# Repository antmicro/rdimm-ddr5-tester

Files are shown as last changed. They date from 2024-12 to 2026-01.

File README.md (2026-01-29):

# Data Center RDIMM DDR5 Tester

Copyright (c) 2021-2026 [Antmicro](https://antmicro.com)



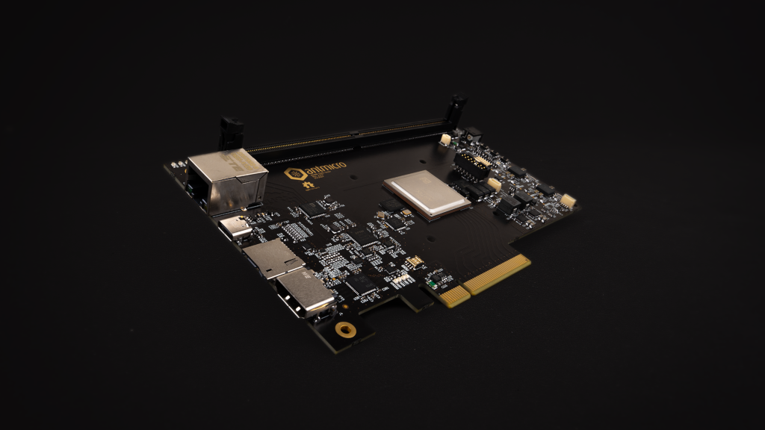
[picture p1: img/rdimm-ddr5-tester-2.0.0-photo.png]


## Overview

This project contains open hardware KiCad design files for an experimental, FPGA-based platform for interfacing with RDIMM DDR5 RAM modules.
The latest design revision (Rev.2.x) features an AMD Artix UltraScale Plus FPGA.
The design files are now being verified with a small series of prototypes.
The [previous revision](https://github.com/antmicro/ddr5-tester/releases/tag/rev.1.0.1-production) (Rev.1.x) was built around an AMD (Xilinx) Kintex-7 FPGA and the design files were verified with prototypes.
This hardware DDR5 testing platform integrates with the open source [Rowhammer Tester](https://github.com/antmicro/rowhammer-tester) project.

## Project structure

The main repository directory contains KiCad PCB project files, a LICENSE and README.
The remaining files are stored in the following directories:

* `img` - contains graphics for this README
* `assets` - contains visual assets for showcasing this design on [Open Hardware Portal](https://openhardware.antmicro.com/boards/data-center-rdimm-ddr5-tester/?view=top-ortho&tab=features).

## Key features

* Artix Ultrascale plus FPGA (AU25P)
* RDIMM DDR5 memory slot
* PCIe 8x Edge connector
* HDMI output connector
* Ethernet RJ45 connector with 1GbE transceiver
* USB-C debug connector with FT4232HQ FTDI USB controller
* JTAG connector
* microSD card slot
* 16 MBytes S25FL128S QSPI FLASH memory
* IS66WVH16M8DBLL HyperRAM
* External 7-15V DC power input

## License

This project is published under the [Apache-2.0](LICENSE) license.

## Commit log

2024-09-24 [#65754] Rev 2.0.0 Initial commit - source design files from so-dimm-ddr5-tester e0a54f86
    [DDR5.kicad_sch, config-spi.kicad_sch, data-center-rdimm-ddr5-tester.kicad_sch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]
2024-09-24 [#65754] Update PCB outline and rename the board
    [rdimm-ddr5-tester-ultrascale-plus.kicad_sch]
2024-09-24 [#65754] Replace so-dimm with rdimm connector
    [ddr5-rdimm.kicad_sch, rdimm-ddr5-tester-ultrascale-plus.kicad_sch]
2024-09-25 [#66311] Add XCAU25P. Reconnect configuration bank 0
    [fpga-bank-14.kicad_sch, fpga-banks-32-34.kicad_sch, fpga-config.kicad_sch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]
2024-09-25 [#66300] Add recommended FPGA supply voltages
    [fpga-power.kicad_sch]
2024-09-25 [#66312] Reconnect PCIe to GTX 224
    [fpga-mgt.kicad_sch]
2024-09-25 [#66329] Replace memory connector on PCB
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2024-09-26 [#66300] Connect supply domains to FPGA. Adjust decoupling
    [fpga-power.kicad_sch]
2024-09-26 [#66312] Reconnect GTY 224 and 225 for x8 PCIe configuration
    [fpga-mgt.kicad_sch]
2024-09-26 [#66329] Replace the FPGA on PCB
2024-09-26 [#66312] Connect x8 PCIe
    [data-center-rdimm-ddr5-tester.kicad_sch, fpga-mgt.kicad_sch, pcie-connector.kicad_sch]
2024-09-26 [#66329] Replace PCIe connector
2024-09-26 [#66329] Designate the heat sink as mechanical
    [data-center-rdimm-ddr5-tester.kicad_sch]
2024-09-27 [#66311] Add TMP451 remote temperature sensor
    [fpga-config.kicad_sch]
2024-09-27 [#66300] Start reconnecting power supply to support US+ voltages and power sequence
    [supply.kicad_sch]
2024-09-30 [66521] Rename kicad_sch file
    [data-center-rdimm-ddr5-tester.kicad_sch, fpga-hp-banks.kicad_sch]
2024-09-30 [#66300] Add 30A VCCINT supply
    [supply.kicad_sch]
2024-09-30 [#66521] Add pinout rev.1.1.0 connection to the schematic
    [fpga-hp-banks.kicad_sch]
2024-10-01 [#66521] Connect labels to DDR5 connector - define DDR5_RDIMM bus
    [data-center-rdimm-ddr5-tester.kicad_sch, ddr5-rdimm.kicad_sch, fpga-hp-banks.kicad_sch]
2024-10-01 [#66300] Finish reconnecting power supply to support US+ voltages and power sequence
    [supply.kicad_sch]
2024-10-23 [#66311] Replace HyperRam and Flash with 1V8 parts. Add 1V25 ADC VREF for core temp measurement (internal)
    [fpga-config.kicad_sch, fpga-power.kicad_sch, hyperram-flash.kicad_sch]
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2024-10-23 [#66521] Rename DQS pairs
    [ddr5-rdimm.kicad_sch, fpga-hp-banks.kicad_sch]
2024-10-23 [#66521] Add Layout for DDR5 A.DQ[0..15]
    [data-center-rdimm-ddr5-tester.kicad_sch, fpga-hp-banks.kicad_sch]
2024-10-23 [#66521] Add Layout for DDR5 B.DQ[24..31]
    [fpga-hp-banks.kicad_sch]
2024-10-23 [#66727] Reconnect HyperRam and ETH RGMII to HP bank 67
    [fpga-bank-12.kicad_sch, fpga-hp-banks.kicad_sch]
2024-10-23 [#66727] Reconfigure ETH PHY IO voltage to 1V8
    [ethernet.kicad_sch]
2024-10-23 [#66521] Add Layout for DDR5 Channel B
    [fpga-hp-banks.kicad_sch]
2024-10-23 [#66521] Add Layout for DDR5 A.DQ[0..23]
    [fpga-hp-banks.kicad_sch]
2024-10-23 [#66300] Replace MGTACC and MGTAVTT high side current measurement resistor, optimize decoupling
    [fpga-power.kicad_sch, supply.kicad_sch]
2024-10-23 [#66300] Replace power measurement IC's with PAC1720 and PAC1944. Split supply sheet to hierarchical structure. Add missing VCCINT pull-up resistors. Change power meters supply to 3V3_AON
    [dc-dc-aux-mgt.kicad_sch, dc-dc-io.kicad_sch, dc-dc-vccint.kicad_sch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]
2024-10-23 [#66312] Add HDMI driver. Connect TMDS to GTH quad 226
    [fpga-mgt.kicad_sch]
2024-10-23 [#66521] Add Layout for DDR5 B.CB[0..7]
    [fpga-hp-banks.kicad_sch]
2024-10-23 [#66521] Add Layout for DDR5 A.DQ[23..31]
    [fpga-hp-banks.kicad_sch]
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2024-10-23 [#66300] Replace HDMI output driver to SN75DP159
    [fpga-mgt.kicad_sch]
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2024-10-23 [#66727] Move remaining signals to HD banks sheet
    [fpga-hd-banks.kicad_sch]
2024-10-23 [#66727] Finish connecting HDMI driver. Add SD card logic level converter. Add SD 3.0 support
    [data-center-rdimm-ddr5-tester.kicad_sch, fpga-mgt.kicad_sch, hdmi-sd-card.kicad_sch]
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2024-10-23 [#66727] Change FTDI JTAG voltage level to 1V8
    [debug-ftdi.kicad_sch]
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2024-10-23 [#67016] Add RGMII, Hyper Ram and SD card schematic connection
    [data-center-rdimm-ddr5-tester.kicad_sch, fpga-hp-banks.kicad_sch]
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2024-10-23 [#66311] Connect 1V25 VREF negative signal to GND
    [fpga-config.kicad_sch]
2024-10-23 [#66311] Start connecting HDMI RX to GTH226 quad
    [fpga-mgt.kicad_sch, hdmi-sd-card.kicad_sch]
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2024-10-23 [#66727] Fix schematic errors
    [dc-dc-vccint.kicad_sch, fpga-config.kicad_sch, fpga-hp-banks.kicad_sch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]
2024-10-23 [#66727] Route VCCINT sense. Route VREF. Place supply power meters circuits
    [dc-dc-vccint.kicad_sch, fpga-config.kicad_sch]
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2024-10-23 [#67402] Connect low speed signals and interfaces to the HD banks
    [data-center-rdimm-ddr5-tester.kicad_sch, ddr5-rdimm.kicad_sch, fpga-hd-banks.kicad_sch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]
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2024-10-23 [#67402] Connect low speed signals and interfaces to the HD banks. Optimize connection in bank 86
    [data-center-rdimm-ddr5-tester.kicad_sch, fpga-mgt.kicad_sch]
2024-10-23 [#66727] Minor schematic improvements. Finish routing right side of the board
    [ddr5-rdimm.kicad_sch, fpga-config.kicad_sch, fpga-hd-banks.kicad_sch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]
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2024-10-23 [#67532] Clean DRC. Optimize power planes, EMC concept and LS/HS routing
    [dc-dc-aux-mgt.kicad_sch, fpga-config.kicad_sch, fpga-power.kicad_sch]
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2024-10-25 [#67725] Update fpga-mgt sheet - change HDMI connection
    [fpga-mgt.kicad_sch]
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2024-10-28 [#67725] Import review changes to PCB. Minor schematic fix
    [data-center-rdimm-ddr5-tester.kicad_sch, dc-dc-aux-mgt.kicad_sch, hdmi-sd-card.kicad_sch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]
2024-10-29 [#68016] Revert I2C translator to PCA9517ADP
    [i2c.kicad_sch]
2024-10-29 [#68016] Mark U36 and its circuit as populated
    [dc-dc-vccint.kicad_sch]
2024-10-29 [#68016] Remove series resistance from the SD card lanes
    [hdmi-sd-card.kicad_sch]
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2024-10-29 [#68016] Fix Power supply short
    [fpga-power.kicad_sch]
2024-10-29 [#67408] Update layout for I3C, SDcard and HDMI aux signals
    [fpga-hd-banks.kicad_sch, hdmi-sd-card.kicad_sch, i2c.kicad_sch]
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2024-10-30 [#67824] Finish length matching SD card interface. Place and route parts after the review. Clean DRC errors. Improve silkscreen
2024-10-31 [#67824] Finish length matching SPI flash interface. Add DDR5 power control transistors. Finish silkscreen labels replacement
    [ddr5-rdimm.kicad_sch, fpga-hd-banks.kicad_sch]
2024-10-31 [#68016] Solve ERC warrings and errors
    [data-center-rdimm-ddr5-tester.kicad_sch, dc-dc-aux-mgt.kicad_sch, dc-dc-io.kicad_sch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]
2024-11-04 [#68199] Start implementing changes after the PCB review
    [dc-dc-vccint.kicad_sch, ethernet.kicad_sch, fpga-config.kicad_sch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]
2024-11-04 [#68199] Finish implementing changes after the PCB review
    [fpga-config.kicad_sch]
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2024-11-05 [#68088] Fix overlapping silkscreen
2024-11-06 [#68088] Add second HDMI_VDD supply option. Minor PCB improvements
    [hdmi-sd-card.kicad_sch]
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2024-12-09 [#69518] Fix Q20 configuration
    [dc-dc-vccint.kicad_sch, debug-ftdi.kicad_sch]
2024-12-09 [#69629] Fix DNP attributes
    [data-center-rdimm-ddr5-tester.kicad_sch, dc-dc-aux-mgt.kicad_sch, dc-dc-io.kicad_sch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]
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2024-12-10 [#69547] Replace VCCINT feed-forward capacitor to 22p
    [dc-dc-vccint.kicad_sch]
2024-12-13 [#69798] Fix I2C adresses descriptions on the schematic
    [dc-dc-aux-mgt.kicad_sch, dc-dc-vccint.kicad_sch, fpga-config.kicad_sch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]
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2024-12-13 [#69493] Replace DC input power connector
    [supply.kicad_sch]
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2024-12-23 [#70553] Post-review fixes
    [dc-dc-io.kicad_sch, supply.kicad_sch]
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2025-07-14 Correct company name in project files
    [data-center-rdimm-ddr5-tester.kicad_sch, dc-dc-aux-mgt.kicad_sch, dc-dc-io.kicad_sch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]
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2026-05-21 [#89070] Replace ETH connector. Bump revision and dates
    [data-center-rdimm-ddr5-tester.kicad_sch, dc-dc-aux-mgt.kicad_sch, dc-dc-io.kicad_sch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]
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2026-05-25 [#97338] Fix malformed DNP properties
    [dc-dc-aux-mgt.kicad_sch, dc-dc-io.kicad_sch, dc-dc-vccint.kicad_sch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]
